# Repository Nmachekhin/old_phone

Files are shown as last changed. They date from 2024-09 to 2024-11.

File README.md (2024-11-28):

Device User Manual

1) Construction
The top of the phone houses the handset, which presses the "hang up" button when placed down. The front panel features a rotary dial for entering numbers. It also includes a battery charge indicator with three sections:
Red: Overvoltage.
Black: Full charge.
Green: Normal battery range.
On the back of the phone, there is a power button and a USB Type-C port for charging. Below the handset cradle on the back is a window that allows the user to see the internal electronics in operation.

2) Powering On/Off and Charging
To turn the device on or off, press the button located on the back panel. Check the charge indicator to verify operation; it should move away from the far-left position. Alternatively, look through the rear window for illuminated red indicators inside.
If the needle does not move or moves only slightly when powered on, and the internal indicators are off, the battery is likely discharged, requiring a recharge.
Charge the device via USB Type-C using a PowerDelivery protocol at 9V and up to 2.5A. When charger is connected, a blue indicator near the port will light up, signaling successful connection. A fully charged battery is indicated when the charge meter enters the red zone. After disconnecting the charger, the indicator should remain in the green zone.
The device is equipped with overcharge protection, so remaining in the red zone while connected to a charger is not dangerous.

3) Receiving/Ending a Call
To keep the device ready for incoming calls, place the handset in its cradle on the body. When the phone rings, pick up the handset to accept the call. The connection will be established almost immediately.
To end a call, either return the handset to its cradle or manually press the "hang up" button. If the call ends without placing the handset down, a series of short beeps will sound in the receiver.

4) Ending a Call Manually
If manually pressing the "hang up" button, wait for a sound signal (a short beep). If physically placing the handset back, allow at least one second for the system to process.

5) Making a Call
To make an outgoing call:
1.Pick up the handset and wait for a long beep, indicating the device is ready.
2.Begin entering the number; the beep will stop as you start dialing.
3.Insert your finger into the hole corresponding to the desired digit and rotate the dial clockwise until your finger reaches the metal stop. Release the dial and allow it to return to its starting position before dialing the next digit.
4.Do not begin entering the next digit until the dial stops moving and the clicking sound ceases.

After completing the number, wait approximately 4 seconds for a short beep in the receiver, which signals the start of the outgoing call.
In case of an incorrect entry, hang up and start dialing the number again.

6) Unforeseen Situations
If the device malfunctions or experiences a software issue, hang up the handset. If the issue persists, turn the device off and on again.
If smoke, sparks, or damage to the device are observed, immediately turn it off, implement fire safety measures if necessary, and promptly contact the manufacturer.

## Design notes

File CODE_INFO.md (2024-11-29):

advanced_dial_test:
Test script for new dialing algorytm.

initialisation_test:
Basic ininiation and sim communication test, can be used for manual control of sim module.

main:
Main code for device operation.

main.ino:
Executable file that keeps track after system and sim module statuses, uses other mosules according to situation. It opperates to state varriables, that are independent: global state describes state of arduino, and sim state describes state of sim module and is read from it. It allows arduino to react on diffrent scenarious and sudden changes. Global timer allows for all modules to be in sync with each other, no metter wat time it takes to execute them (Exept the part with dial reading). Function tha reads dial has the highest priority and when has to be used main calls it and only it.

Dial.h / Dial.ino:
Module that is responsible for entering number with rotary dial.
int get_reading() - returns readings from dial pin.
void operate_dial(unsigned long, SimModule&) - detects pulses of from dial, needs global timer for operation and sim module module for canseling tone when entering number. It uses global timer only for calculating delay after uiser finishes entering number, sepparate timer is used for detecting pulses, it is more precise and is using microseconds. Code detects series of pulses, and then filters out only the real one to convert for input. The criteria is: pulse has to be longer then 11000 microsecconds and to be bigger then two neares neibours. This function needs to be called as frequent as possible.
void reset_timers(unsigned long) - sets internal timer to current time.
bool ready_to_call(unsigned long) - returns true if there is number entered and delay after last input has passed.
String get_number() - returns entered number.
void reset_number() - sets endered number to empty.

SimCommands.h / SimCommands.ino
Module that is responsible for communication with sim module using at commands.
Constructor sends commands to sim module with all required settings.
void stop_tone() - stops any tone what is playing through speaker.
void play_tone(short, unsigned int) - plays tone through speakers, takes tone type and duration in millisecconds as parameters.
void hang() - commands module ho terminate call.
void accept() - commands module to accept incomming call.
void dial(String) - dials selected number (if there are call in progress already, it will be terminated).
void check_status(unsigned long, SimStatus&) - checks status of sim module, takes global timer and sim status as parameters, sets sim status to corresponding one. It sends check status command to sim module and awaits for answer, according to which sets sim status. Because of waiting for response, this function may take a while to opperate, and it is called only when dial is not in use. Also it has its own delay between requests, to prevent spamming.

SoundController.h / SoundController.ino
const unsigned char ring_sound[] PROGMEM - array of pwm values to play sound using only arduino. Stored in program memory section.
void play_ring(unsigned long) - plays ring one time, takes global timer to not start playback again when already playing.
play_silence(unsigned long) - pulls playback pin to low to prevent aplifyer playing static noises.

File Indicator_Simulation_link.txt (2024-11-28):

https://www.falstad.com/circuit/circuitjs.html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

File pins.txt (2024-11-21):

Розпіновка Arduino Nano:
	D2 - кнопка "покласти слухавку" (INPUT_PULLUP)
	D3 - кнопка дискового набору номера (INPUT_PULLUP)
	D11 - дані до підсилювача звуку (OUTPUT)
	D7 - прийом даних з модуля сімкарти (INPUT)
	D8 - надсилання даних на модуль сімкарти (OUTPUT)
	GRND - земля
	5V - живлення

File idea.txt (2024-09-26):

Опис ідеї:
		Реалізувати в корпусі старого стаціонарного телефону з дисковим набором номеру можливість здійснювати та приймати
	дзвінки по мережі мобільного зв'язку, забезпечити можливість автономної роботи та зберегти зовнішній вигляд близьким до оригіалу.
	робити можливість перенабору номеру з останнього вхідного та останнього вихідного дзвінка.

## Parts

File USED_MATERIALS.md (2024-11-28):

While creating code for the device I was using:
1)sim800l datasheet https://www.alldatasheet.com/datasheet-pdf/pdf/1741389/SIMCOM/SIM800L.html
2)sim800l at command manual https://microchip.ua/simcom/2G/SIM800%20Series_AT%20Command%20Manual_V1.12.pdf
3)"How to send message and make a phone call from arduino with sim800l" https://medium.com/@robotamateur123/how-to-send-a-message-and-make-a-phone-call-from-arduino-with-sim800l-f65db28a5c60
4)Falstad circuit simulator https://www.falstad.com/
5)Circuit Diagrams https://www.circuit-diagram.org/
6)PCM library for playing sound from arduino https://github.com/damellis/PCM

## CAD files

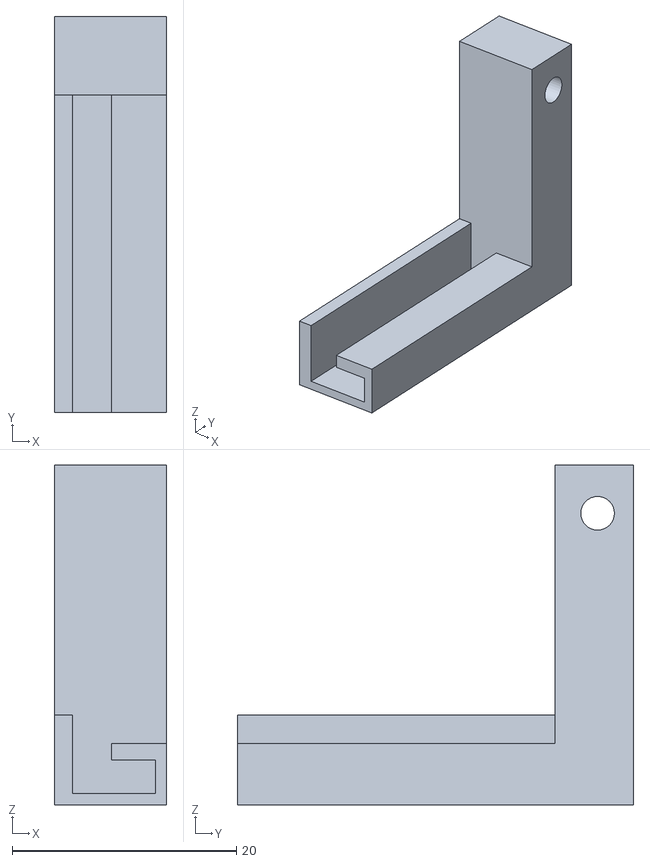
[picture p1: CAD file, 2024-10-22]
models/Radiator mount.stl
10.0 x 35.3 x 30.3

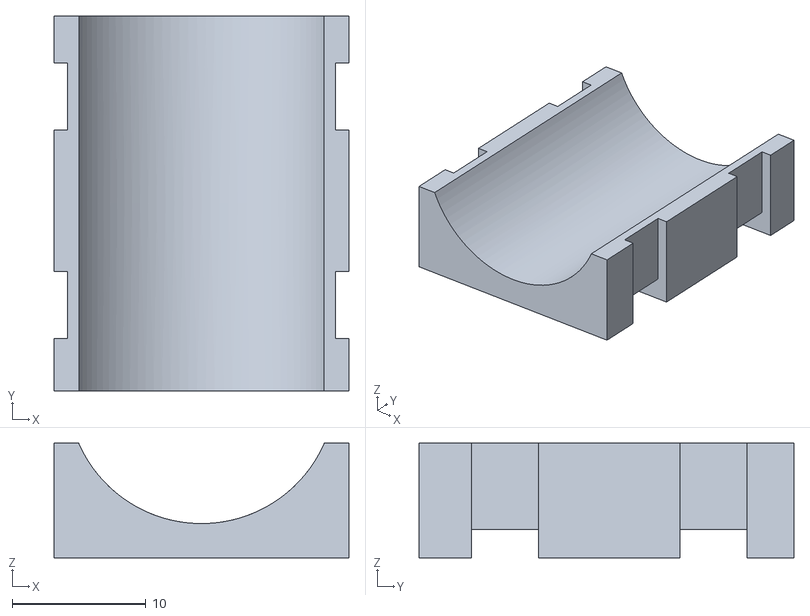
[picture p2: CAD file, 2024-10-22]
models/Battery holder.stl
22.0 x 28.0 x 8.55

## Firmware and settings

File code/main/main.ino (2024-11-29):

#include "Dial.h"
#include "SimCommands.h"
#include "SoundController.h"

bool call_started=false;
const short int HANG_PIN=2;
const short int DIAL_PIN=3;

unsigned long global_timer;



SimModule sim800l(7, 8);
Dial PhoneDial(DIAL_PIN);
SoundController Amp=SoundController();

enum MainStatus{
  UNKNOWN_STATUS=0,
  IDDLE=1,
  DIALING=2,
  CALLING=3,
  SPEAKING=4,
  OPONENT_HANGED=5
};

MainStatus status=UNKNOWN_STATUS;

//AT+CPAS

SimStatus sim_status=UNKNOWN;

void setup() {
  Serial.begin(9600);
  pinMode(HANG_PIN, INPUT_PULLUP);
  pinMode(DIAL_PIN, INPUT_PULLUP);
  Serial.println("Initialization is complete!");
  global_timer=millis();
}


bool hanged()
{
    return !digitalRead(HANG_PIN);
}

void to_iddle()
{
  sim800l.play_tone(1,200);
  sim800l.hang();
  
  status=IDDLE;
  PhoneDial.reset_number();
  //Serial.println("hanged");
  call_started=false;
}

void answer()
{
  sim800l.stop_tone();
  status=SPEAKING;
  sim800l.accept();
}


void call()
{
    sim800l.play_tone(1,200);
    sim800l.hang();
    sim800l.dial(PhoneDial.get_number());
    status=SPEAKING;
}

void loop() {

  //update gllobal timer
  global_timer=millis();

  //updating dial
  if(!hanged() && status==DIALING) 
  {
    PhoneDial.operate_dial(global_timer, sim800l);
    //Serial.println(PhoneDial.get_number());
    if (PhoneDial.ready_to_call(global_timer)) 
    {
      //Serial.println(PhoneDial.get_number());
      call();
    }
    return;
  }

  //check weather hanged
  if (hanged() && status!=IDDLE) to_iddle();

  //playing coresponding sounds
  if (hanged() && sim_status==INCOMMING) Amp.play_ring(global_timer);
  else Amp.play_silence(global_timer);

  //entering dial mode
  if (!hanged() && status==IDDLE && sim_status==READY) 
  {
    status=DIALING;
    sim800l.play_tone(1,15200000);
    PhoneDial.reset_timers(global_timer);
  }

  //checking weather oponent has ended a call
  if (!hanged() && status==SPEAKING && sim_status!=INCALL && call_started)
  {
    status = OPONENT_HANGED;
    sim800l.play_tone(3,15200000);
  }

  //answering to incoming call
  if (!hanged() && (status==IDDLE || status==DIALING) && sim_status==INCOMMING) answer();

  //checking sim module status
  if (status==IDDLE || status==SPEAKING)
    sim800l.check_status(global_timer, sim_status);


  if (status==SPEAKING && sim_status==INCALL)
    call_started=true;
}

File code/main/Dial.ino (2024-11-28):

#include "Dial.h"

Dial::Dial(const short int dp)
{
  dial_pin=dp;
  pinMode(dial_pin, INPUT_PULLUP);
}

int Dial::get_reading()
{
  return digitalRead(dial_pin);
}


void Dial::operate_dial(unsigned long global_timer, SimModule& sim800l){
  if (!last_btn_state && get_reading())
  {
    last_btn_state = true;
    tick_timer = micros();
    dial_standby_timer=global_timer;
    sim800l.stop_tone();
  }
  if (last_btn_state && !get_reading())
  {
    last_btn_state = false;
    tick_arr[len]=micros()-tick_timer;
    len++;
  }
  if(len>1 && !last_btn_state && micros()-tick_timer>dial_btn_delay*1000)
  {
    current_number=0;
    for(int i=1; i<len-1; i++)
      if (tick_arr[i]>tick_arr[i-1] && tick_arr[i]>tick_arr[i+1] && tick_arr[i]>=11000)
        {
            //Serial.println(ar[i]);
            current_number++;
        }
    
    len=1;
    dialed_number+=current_number%10;
    //Serial.println(dialed_number);
  }
  
}

bool Dial::ready_to_call(unsigned long global_timer)
{
  return global_timer-dial_standby_timer>=dial_before_call_delay && dialed_number!="";
}


String Dial::get_number()
{
  return dialed_number;
}

void Dial::reset_number()
{
  dialed_number="";
}

void Dial::reset_timers(unsigned long global_timer)
{
    dial_timer=global_timer;
    dial_standby_timer=global_timer;
}

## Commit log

2024-10-15 reserved i2c
2024-10-22 added battery holder
    [Battery holder.stl]
2024-10-22 added radiator mount
    [Radiator mount.stl]
2024-11-05 Found code for basic communication with sim800l, started to develop own initialisation and operation script for arduino
2024-11-21 Added final functional, modifyed pin layout
2024-11-21 Splitted code into modules, made buzz more silent
    [Dial.ino, SimCommands.ino, main.ino]
2024-11-21 minor tweaks and bugfixes
    [SimCommands.ino, main.ino]
